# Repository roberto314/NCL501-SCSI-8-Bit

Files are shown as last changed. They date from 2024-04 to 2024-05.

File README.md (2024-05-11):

# NCL501-SCSI-8-Bit
Recreation of a bootable ISA 8-Bit SCSI Card.

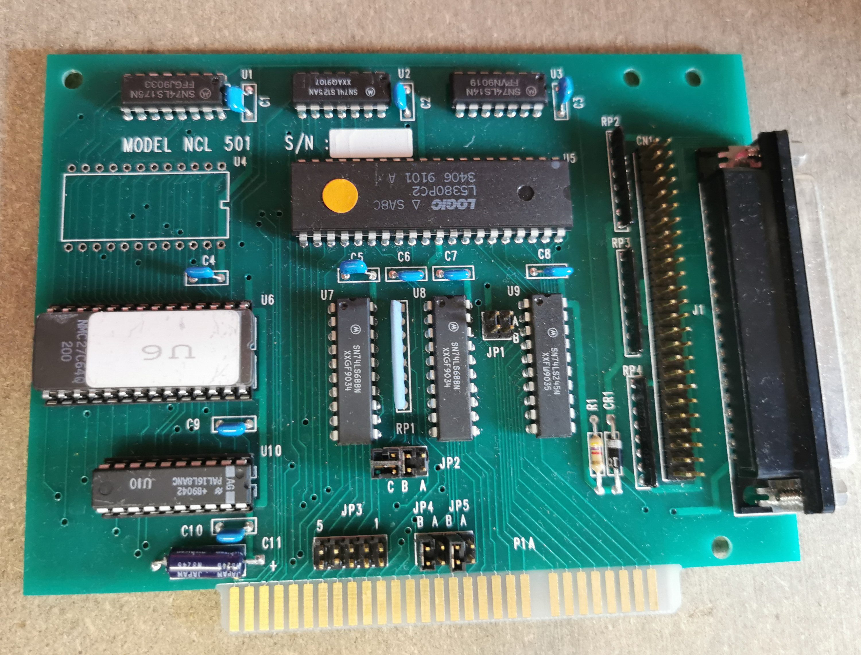
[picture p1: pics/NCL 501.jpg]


There is one PAL on the Card (PAL16L8), it is protected unfortunately.
A dump has been done and the equations have been recreated.
They might be wrong.
BIOS EPROM is a 27C64 Type, RAM is not poplated but a 6116 might be used (24-pin Socket).

[Schematic](schematic/NCL501/pdf/NCL501.pdf)

The new card looks like this:
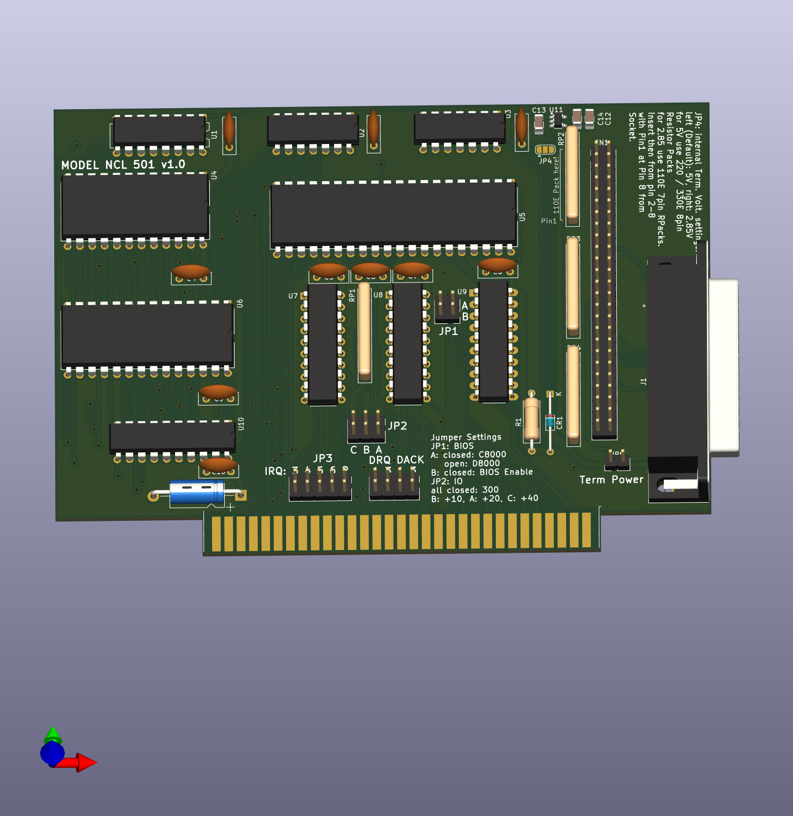
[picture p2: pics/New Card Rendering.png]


or the real thing:
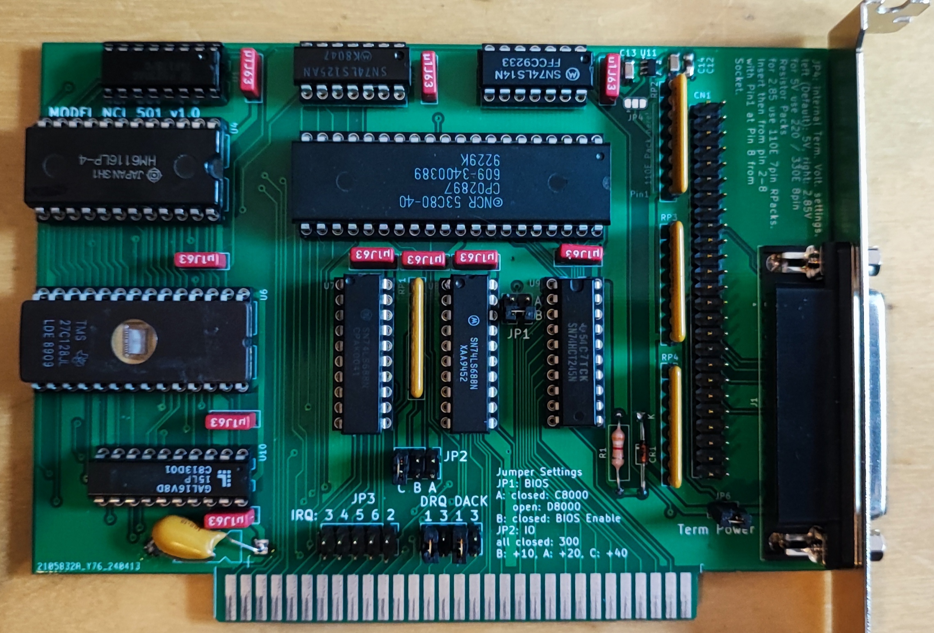
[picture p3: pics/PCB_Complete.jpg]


Changes are:

* active termination or passive Termination possible.
* Term Power with Jumper
* DB25 Connector instead of DB37
* smaller (97.75 x 135mm)

For active Termination the following Parts are needed:

    - C12: 470p Footprint 1206

    - C13, C14: 100n Footprint 1206

    - U11: MIC5219 2.85V Regulator SOT-23-5

This Adapter has some serious shortcomings:

In my Computer (micro8088) it ONLY works with DRQ/DACK 3, ROM @ D8000 and IO @ 330!
IRQ doesn't matter also the RAM onboard is not necessary.

I tested the following Images:

Heads and Sectors working:

spf = sectors/fat, spc = sectors/cluster

* C:  79 / H:8  / S:32 10 MB (FAT12) works
* C:  95 / H:8  / S:32 12 MB (FAT12) works
* C:  39 / H:16 / S:32 10 MB works
* C:  22 / H:15 / S:63 10 MB doesn't work (non-system disk)
* C:  21 / H:16 / S:62 10 MB doesn't work (non-system disk)
* C:  21 / H:16 / S:63 10 MB doesn't work (non-system disk)
* C:  63 / H:16 / S:32 16 MB (FAT12) works
* C:  67 / H:16 / S:32 17 MB (FAT16/4) doesn't work (non-system disk)
* C:  67 / H:16 / S:32 17 MB (FAT16/4) with spf=0x40 instead of 0x100: works
* C: 127 / H:16 / S:32 32 MB (FAT16/4) with spf=0x40 instead of 0x100: works
* C: 135 / H:16 / S:32 33 MB (FAT16/6) with spf=0x60 instead of 0x100: works
* C: 255 / H:16 / S:32 64 MB (FAT16/6) with spf=0x40 instead of 0x100: doesn't work (non-system disk)
* C: 255 / H:16 / S:32 64 MB (FAT16/6) with spf=0x40 instead of 0x100: doesn't work (non-system disk)
* C: 255 / H:16 / S:32 64 MB (FAT16/6) with spf=0x80 instead of 0x100: works
* C: 507 / H:16 / S:32 127 MB (FAT16/6) with spf=0xFF instead of 0x100: doesn't work (non-system disk)
* C: 507 / H:16 / S:32 127 MB (FAT16/6) with spf=0xFE instead of 0x100: doesn't work (non-system disk)
* C: 359 / H:16 / S:32 90 MB (FAT16/6) with spf=0xC0 instead of 0x100, spc=4: doesn't work
* C: 359 / H:16 / S:32 90 MB (FAT16/6) with spf=0xC0 instead of 0x100, spc=8: doesn't work
* C: 183 / H:16 / S:63 90 MB (FAT16/6) with spf=0xC0 instead of 0x100: doesn't work (non-system disk)
* C: 359 / H:16 / S:32 90 MB (FAT16/6) with spf=0xD0 instead of 0x100: doesn't work, hangs
* C: 359 / H:16 / S:32 90 MB (FAT16/6) with spf=0xE0 instead of 0x100: doesn't work, hangs
* C: 479 / H:16 / S:32 120 MB (FAT16/6) with spf=0xF0 instead of 0x100: doesn't work (non-system disk)
* C: 511 / H:16 / S:32 128 MB (FAT16/6) with spf=0xC0 instead of 0x100: doesn't work
* C: 511 / H:16 / S:32 128 MB (FAT16/6) with spf=0x80, spc=8 instead of 0x100: works
* C: 515 / H:16 / S:32 129 MB (FAT16/6) with spf=0xC0 instead of 0x100: doesn't work
* C: 763 / H:16 / S:32 191 MB (FAT16/6) with spf=0xC0 instead of 0x100: doesn't work
* C: 767 / H:16 / S:32 192 MB (FAT16/6) with spf=0xC0 instead of 0x100: doesn't work
* C:1019 / H:16 / S:32 255 MB (FAT16/6) with spf=0x80,spc=16  works
* C:1023 / H:16 / S:32 256 MB (FAT16/6) with spf=0x80,spc=16  works
* C: 741 / H:16 / S:33 191 MB (FAT16/6) with spf=0xC0 instead of 0x100: doesn't work (non-system disk)
* C: 1006 / H:14 / S:48 330 MB (FAT16/6) with spf=0xC0 instead of 0x100: doesn't work (non-system disk)
* C:  510 / H:16 / S:48 191 MB (FAT16/6) with spf=0xC0 instead of 0x100: doesn't work (non-system disk)
* C:  620 / H:16 / S:62 300 MB (FAT16/6) with spf=0x100,spc=16: doesn't work (non-system disk)
* C:  620 / H:16 / S:62 300 MB (FAT16/6) with spf=0x80,spc=32: doesn't work (non-system disk)
* C:  620 / H:16 / S:62 300 MB (FAT16/6) with spf=0x80,spc=32: doesn't work (non-system disk)
* C:  262 / H:16 / S:63 300 MB (FAT16/6) with spf=0xFC,spc=16: doesn't work (non-system disk)
* C:  262 / H:16 / S:63 300 MB (FAT16/6) with spf=0xC0,spc=16: doesn't work (non-system disk)
* C:  514 / H:32 / S:32 257.5 MB (FAT16/6) with spf=0xFC,spc=16  works
* C: 1005 / H:32 / S:32 503 MB (FAT16/6) with spf=0xFC,spc=16  works
* C: 1001 / H:5 / S:52 127 MB (FAT16/6) with spf=0xC0,spc=8 doesn't work (non-system disk)
* C: 1001 / H:5 / S:52 127 MB (FAT16/6) with spf=0xFC,spc=8 doesn't work (non-system disk)
 
* C: 127 / H:16 / S:32 32 MB doesn't work (non-system disk)
* C: 479 / H:8  / S:32 60 MB doesn't work (non-system disk)
* C: 511 / H:8  / S:32 64 MB doesn't work (non-system disk)
* C: 197 / H:32 / S:32 99 MB (FAT16/4) with spf=0xC0 instead of 0x100: doesn't work (non-system disk)
* C:1023 / H:8  / S:32 128 MB doesn't work (non-system disk)
* C:1023 / H:16 / S:32 256 MB doesn't work (non-system disk)
* C:1019 / H:16 / S:32 255 MB doesn't work (non-system disk)
* C: 511 / H:16 / S:32 128 MB doesn't work (non-system disk)
* C: 511 / H:16 / S:32 128 MB (FAT16/4) with spf=0x40 instead of 0x100: doesn't work (non-system disk)
* C: 503 / H:16 / S:32 126 MB (FAT16/4) with spf=0x40 instead of 0x100: doesn't work (non-system disk)

Limits are: 

* spf Value only 8-bit and only some values are possible.
* Size 503MB for now.

The Card can be hacked to be a SUMO SCSI Card with reasonable effort (by omitting U12-14). Then the ASPI Driver ZHA.SYS and ZDRV.SYS will work.

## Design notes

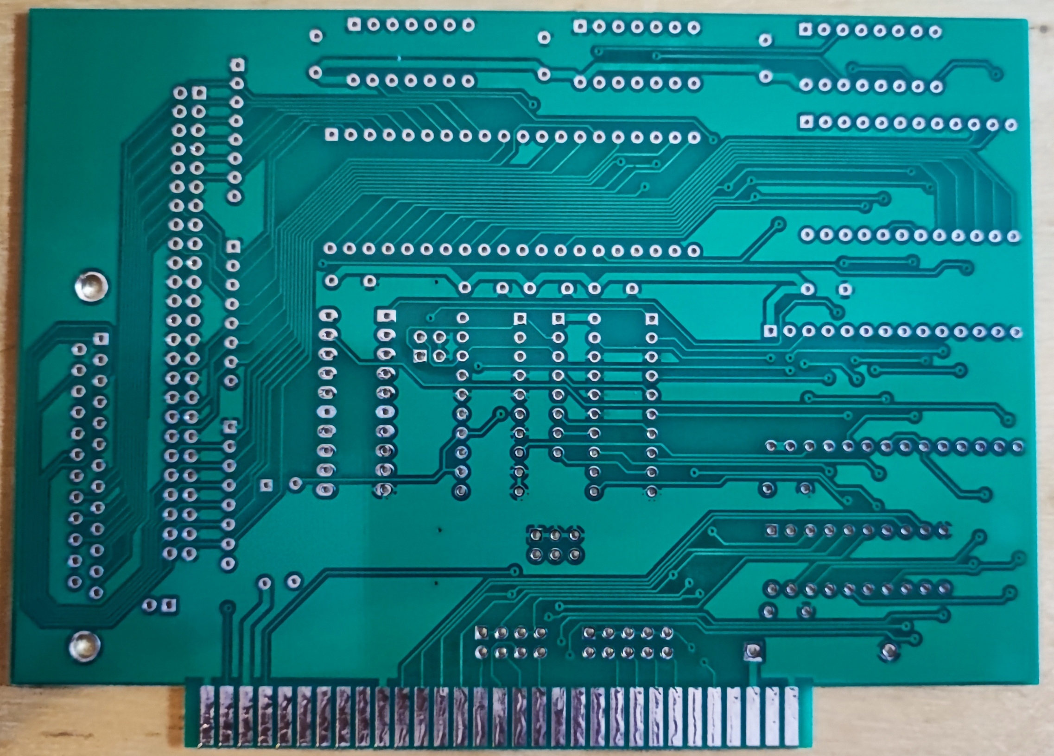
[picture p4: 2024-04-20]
pics/PCB_Back.jpg

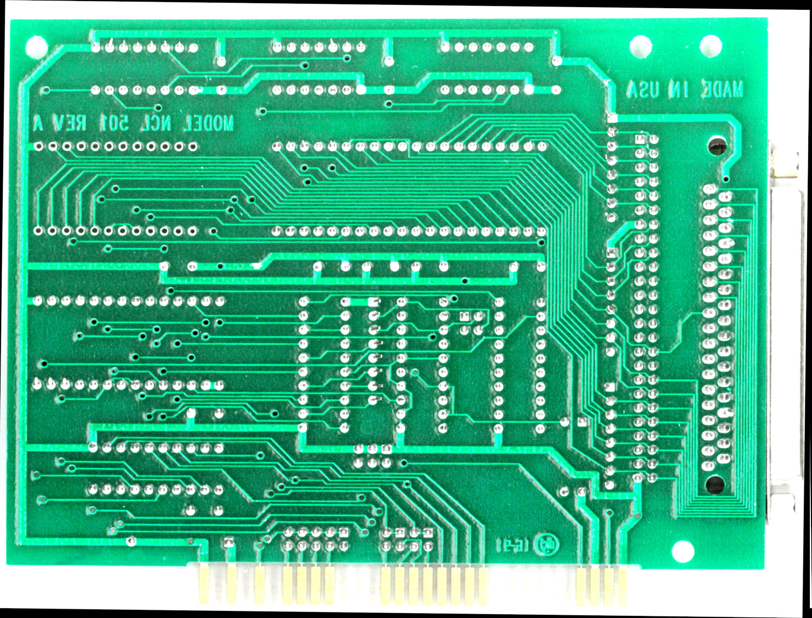
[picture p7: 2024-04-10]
pics/NCL-501_back_lo.jpg

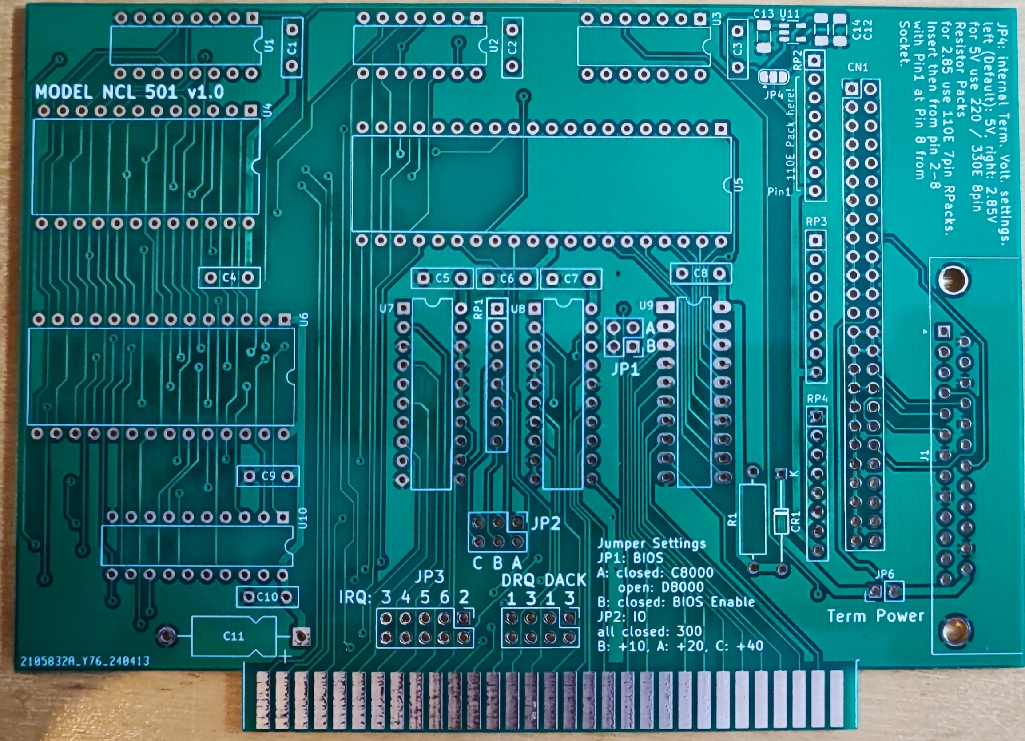
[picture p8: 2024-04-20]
pics/PCB_Front.jpg

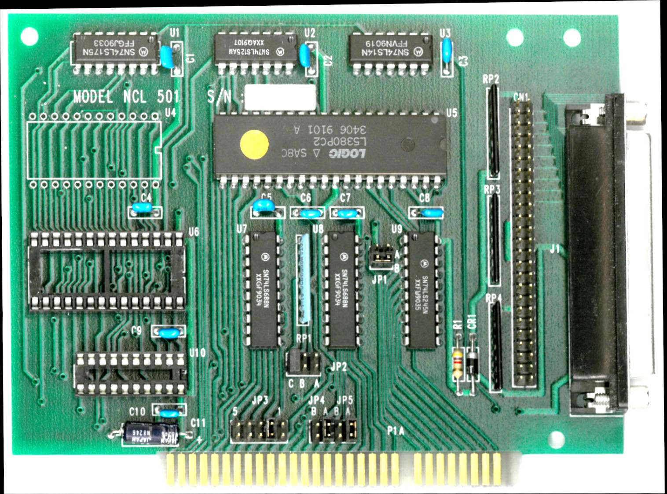
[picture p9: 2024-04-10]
pics/NCL-501_front_lo.jpg

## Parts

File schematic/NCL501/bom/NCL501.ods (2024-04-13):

References | Value | Footprint | Quantity
C1, C2, C3, C4, C5, C6, C7, C8, C9, C10 | 100n | C_Disc_D8.0mm_W2.5mm_P5.00mm | 10
C13, C14 | 100n | C_1206_3216Metric_Pad1.33x1.80mm_HandSolder | 2
C11 | 22u/16 | CP_Axial_L11.0mm_D5.0mm_P18.00mm_Horizontal | 1
C12 | 470p | C_1206_3216Metric_Pad1.33x1.80mm_HandSolder | 1
R1 | 4k7 | R_Axial_DIN0309_L9.0mm_D3.2mm_P12.70mm_Horizontal | 1
U7, U8 | 74LS688 | DIP-20_W7.62mm | 2
U1 | 74LS175 | DIP-16_W7.62mm | 1
U2 | 74LS125 | DIP-14_W7.62mm | 1
U3 | 74LS14 | DIP-14_W7.62mm | 1
U4 | 6116 | DIP-24_W15.24mm | 1
U5 | 53C80 | DIP-40_W15.24mm | 1
U6 | 27C128 | DIP-28_W15.24mm | 1
U9 | 74LS245 | DIP-20_W7.62mm_LongPads | 1
U10 | PAL16L8 | DIP-20_W7.62mm | 1
U11 | MIC5219-2.85YM5 | SOT-23-5 | 1
RP2, RP3, RP4 | 220E/330E | R_Array_SIP8 | 3
CN1 | SCSI Intern | PinHeader_2x25_P2.54mm_Vertical | 1
CR1 | 1N4001 | D_DO-34_SOD68_P12.70mm_Horizontal | 1
JP1 | BIOS | PinHeader_2x02_P2.54mm_Vertical | 1
JP2 | IO | PinHeader_2x03_P2.54mm_Vertical | 1
JP3 | IRQ | PinHeader_2x05_P2.54mm_Vertical | 1
JP4 | TRMPWRSEL | SolderJumper-3_P1.3mm_Bridged12_RoundedPad1.0x1.5mm | 1
JP6 | TermPower | PinHeader_1x02_P2.54mm_Vertical | 1
RP1 | 4k7 | R_Array_SIP8 | 1
J1 | SCSI extern | DSUB-25_Female_Horizontal_P2.77x2.84mm_EdgePinOffset7.70mm_Housed_MountingHolesOffset9.12mm | 1
J2 | Bus_ISA_8bit | BUS_XT | 1
J4 | DACK/DRQ | PinHeader_2x04_P2.54mm_Vertical | 1

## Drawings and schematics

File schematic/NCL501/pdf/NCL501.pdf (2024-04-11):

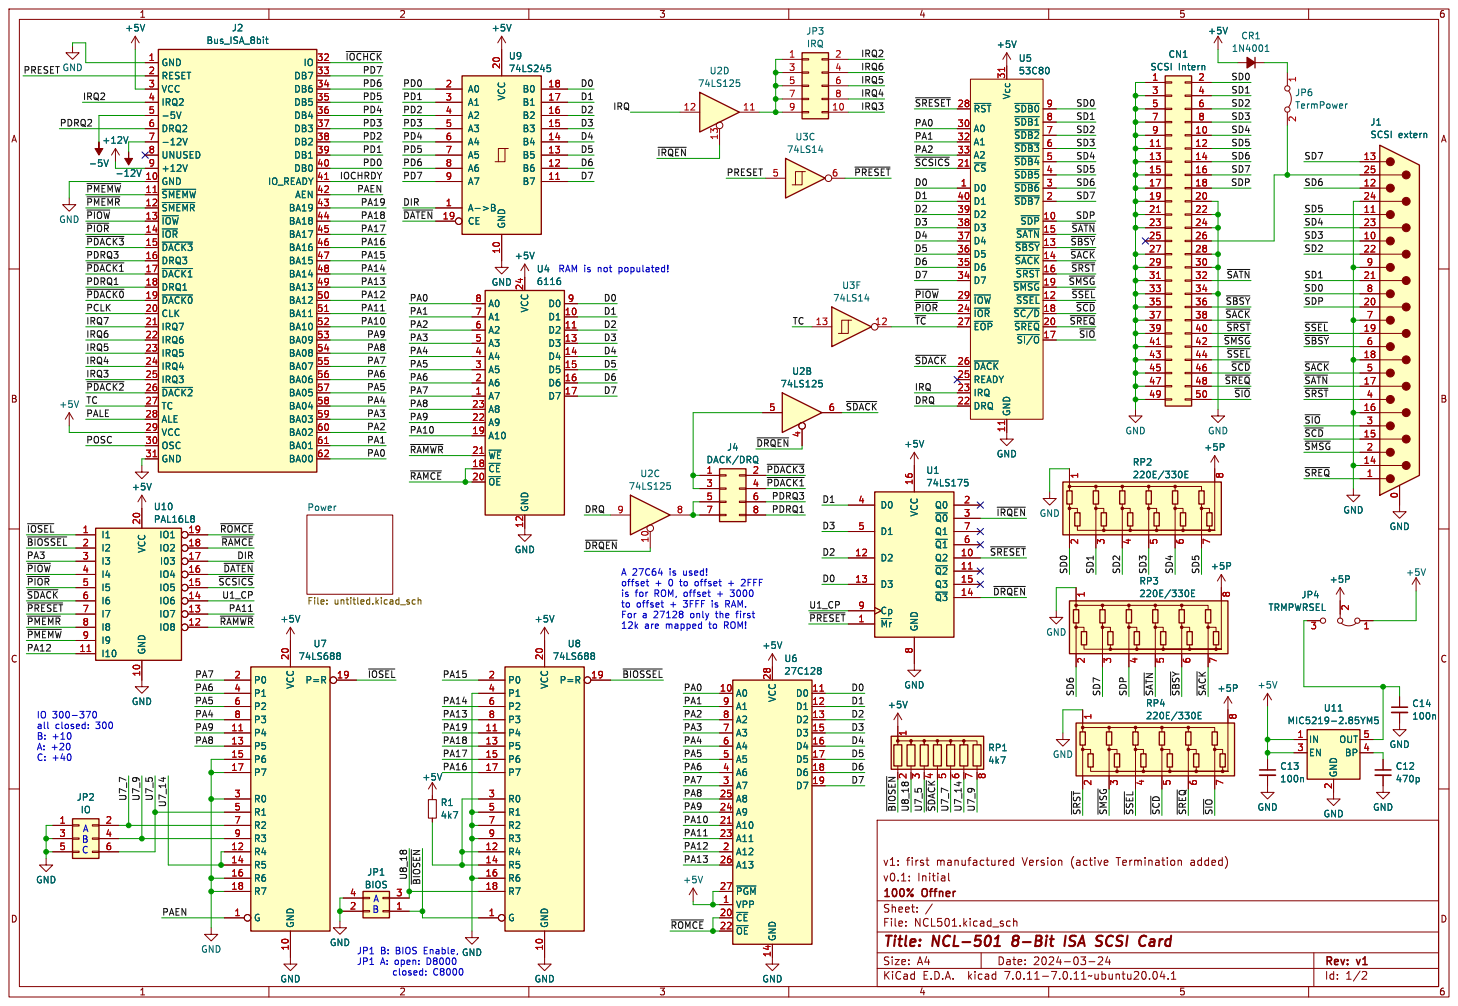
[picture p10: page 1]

J2 Bus_ISA_8bit GND 1 GND 10 ~{SMEMW} 11 ~{SMEMR} 12 ~{IOW} 13 ~{IOR} 14 ~{DACK3} 15 DRQ3 16 ~{DACK1} 17 DRQ1 18 ~{DACK0} 19 RESET 2 CLK 20
IRQ3 25 ~{DACK2} 26 TC 27 ALE 28 VCC 29 VCC 3 OSC 30 GND 31

J2 Bus_ISA_8bit

74LS125 GND 1 GND 10 ~{SMEMW} 11 ~{SMEMR} 12 ~{IOW} 13 ~{IOR} 14 ~{DACK3} 15 DRQ3 16 ~{DACK1} 17 DRQ1 18 ~{DACK0} 19 RESET 2 CLK 20

to offset + 3FFF is RAM. For a 27128 only the first 12k are mapped to ROM! RAM is not populated!

2 EN 3 BP 4 OUT 5 U11 MIC5219-2.85YM5 +5V GND GND

A 27C64 is used! offset + 0 to offset + 2FFF

is for ROM, offset + 3000

2 EN 3 BP 4 OUT 5 GND

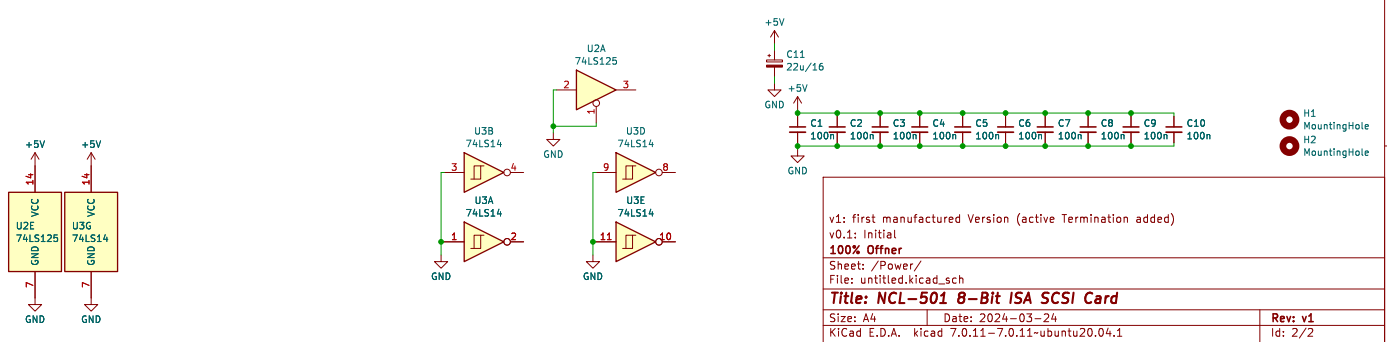
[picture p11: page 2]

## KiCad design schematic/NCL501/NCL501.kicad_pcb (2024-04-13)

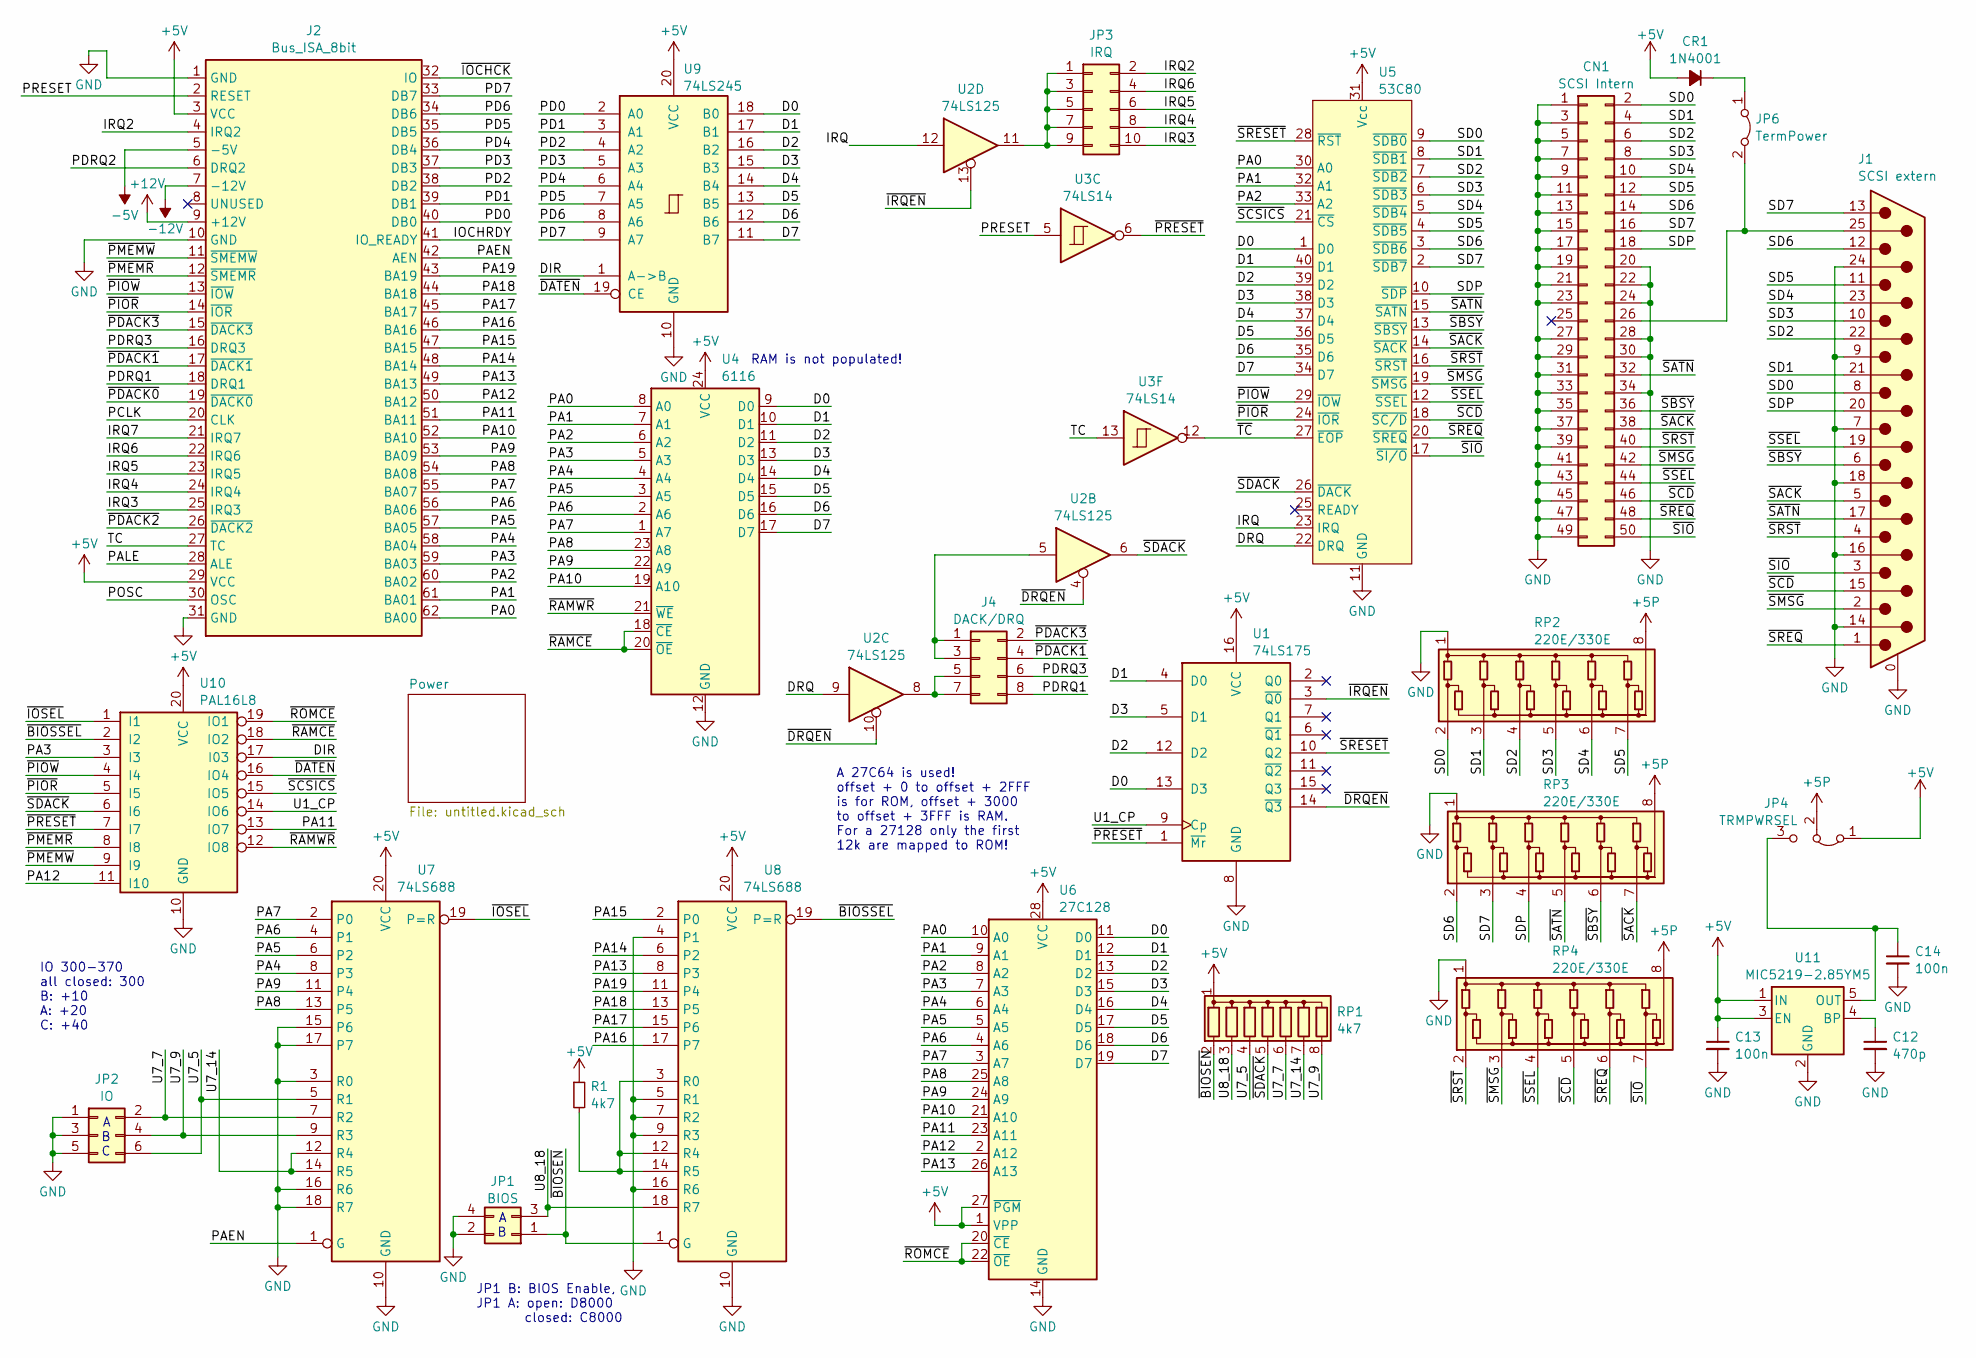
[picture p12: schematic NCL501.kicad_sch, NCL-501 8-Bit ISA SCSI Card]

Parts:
C12: 470p; C_1206_3216Metric_Pad1.33x1.80mm_HandSolder
C13, C14: 100n; C_1206_3216Metric_Pad1.33x1.80mm_HandSolder
CN1: SCSI Intern; PinHeader_2x25_P2.54mm_Vertical
CR1: 1N4001; D_DO-34_SOD68_P12.70mm_Horizontal
J1: SCSI extern; DSUB-25_Female_Horizontal_P2.77x2.84mm_EdgePinOffset7.70mm_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
J2: Bus_ISA_8bit; BUS_XT
J4: DACK/DRQ; PinHeader_2x04_P2.54mm_Vertical
JP1: BIOS; PinHeader_2x02_P2.54mm_Vertical
JP2: IO; PinHeader_2x03_P2.54mm_Vertical
JP3: IRQ; PinHeader_2x05_P2.54mm_Vertical
JP4: TRMPWRSEL; SolderJumper-3_P1.3mm_Bridged12_RoundedPad1.0x1.5mm
JP6: TermPower; PinHeader_1x02_P2.54mm_Vertical
R1: 4k7; R_Axial_DIN0309_L9.0mm_D3.2mm_P12.70mm_Horizontal
RP1: 4k7; R_Array_SIP8
RP2, RP3, RP4: 220E/330E; R_Array_SIP8
U1: 74LS175; DIP-16_W7.62mm
U2: 74LS125; DIP-14_W7.62mm
U3: 74LS14; DIP-14_W7.62mm
U4: 6116; DIP-24_W15.24mm
U5: 53C80; DIP-40_W15.24mm
U6: 27C128; DIP-28_W15.24mm
U7, U8: 74LS688; DIP-20_W7.62mm
U9: 74LS245; DIP-20_W7.62mm_LongPads
U10: PAL16L8; DIP-20_W7.62mm
U11: MIC5219-2.85YM5; SOT-23-5

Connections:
+5P: JP4.2 (C), RP2.8 (COM2), RP3.8 (COM2), RP4.8 (COM2)
+5V: C13.1, CR1.2 (A), J2.3 (VCC), J2.29 (VCC), JP4.1 (A), R1.1, RP1.1 (common), U1.16 (VCC), U4.24 (VCC), U5.31 (Vcc), U6.1 (VPP), U6.27 (~PGM), U6.28 (VCC), U7.20 (VCC), U8.20 (VCC), U9.20 (VCC), U10.20 (VCC), U11.1 (IN), U11.3 (EN); also elsewhere on the board
+12V: J2.9 (+12V)
-5V: J2.5 (-5V)
-12V: J2.7 (-12V)
/D0: U1.13 (D3), U4.9 (D0), U5.1 (D0), U6.11 (D0), U9.18 (B0)
/D1: U1.4 (D0), U4.10 (D1), U5.40 (D1), U6.12 (D1), U9.17 (B1)
/D2: U1.12 (D2), U4.11 (D2), U5.39 (D2), U6.13 (D2), U9.16 (B2)
/D3: U1.5 (D1), U4.13 (D3), U5.38 (D3), U6.15 (D3), U9.15 (B3)
/D4: U4.14 (D4), U5.37 (D4), U6.16 (D4), U9.14 (B4)
/D5: U4.15 (D5), U5.36 (D5), U6.17 (D5), U9.13 (B5)
/D6: U4.16 (D6), U5.35 (D6), U6.18 (D6), U9.12 (B6)
/D7: U4.17 (D7), U5.34 (D7), U6.19 (D7), U9.11 (B7)
/DIR: U9.1 (A->B), U10.17 (I03)
/DRQ: U2.9, U5.22 (DRQ)
/IOCHRDY: J2.41 (IO_READY)
/IRQ: U2.12, U5.23 (IRQ)
/IRQ2: J2.4 (IRQ2), JP3.2
/IRQ3: J2.25 (IRQ3), JP3.10
/IRQ4: J2.24 (IRQ4), JP3.8
/IRQ5: J2.23 (IRQ5), JP3.6
/IRQ6: J2.22 (IRQ6), JP3.4
/IRQ7: J2.21 (IRQ7)
/PA0: J2.62 (BA00), U4.8 (A0), U5.30 (A0), U6.10 (A0)
/PA1: J2.61 (BA01), U4.7 (A1), U5.32 (A1), U6.9 (A1)
/PA2: J2.60 (BA02), U4.6 (A2), U5.33 (A2), U6.8 (A2)
/PA3: J2.59 (BA03), U4.5 (A3), U6.7 (A3), U10.3 (I3)
/PA4: J2.58 (BA04), U4.4 (A4), U6.6 (A4), U7.8 (P3)
/PA5: J2.57 (BA05), U4.3 (A5), U6.5 (A5), U7.6 (P2)
/PA6: J2.56 (BA06), U4.2 (A6), U6.4 (A6), U7.4 (P1)
/PA7: J2.55 (BA07), U4.1 (A7), U6.3 (A7), U7.2 (P0)
/PA8: J2.54 (BA08), U4.23 (A8), U6.25 (A8), U7.13 (P5)
/PA9: J2.53 (BA09), U4.22 (A9), U6.24 (A9), U7.11 (P4)
/PA10: J2.52 (BA10), U4.19 (A10), U6.21 (A10)
/PA11: J2.51 (BA11), U6.23 (A11), U10.13 (IO7)
/PA12: J2.50 (BA12), U6.2 (A12), U10.11 (I10)
/PA13: J2.49 (BA13), U6.26 (A13), U8.8 (P3)
/PA14: J2.48 (BA14), U8.6 (P2)
/PA15: J2.47 (BA15), U8.2 (P0)
/PA16: J2.46 (BA16), U8.17 (P7)
/PA17: J2.45 (BA17), U8.15 (P6)
/PA18: J2.44 (BA18), U8.13 (P5)
/PA19: J2.43 (BA19), U8.11 (P4)
/PAEN: J2.42 (AEN), U7.1 (G)
/PALE: J2.28 (ALE)
/PCLK: J2.20 (CLK)
/PD0: J2.40 (DB0), U9.2 (A0)
/PD1: J2.39 (DB1), U9.3 (A1)
/PD2: J2.38 (DB2), U9.4 (A2)
/PD3: J2.37 (DB3), U9.5 (A3)
/PD4: J2.36 (DB4), U9.6 (A4)
/PD5: J2.35 (DB5), U9.7 (A5)
/PD6: J2.34 (DB6), U9.8 (A6)
/PD7: J2.33 (DB7), U9.9 (A7)
/PDRQ1: J2.18 (DRQ1), J4.8
/PDRQ2: J2.6 (DRQ2)
/PDRQ3: J2.16 (DRQ3), J4.6
/POSC: J2.30 (OSC)
/PRESET: J2.2 (RESET), U3.5
/SD0: CN1.2, J1.8, RP2.2 (R1), U5.9 (~SDB0)
/SD1: CN1.4, J1.21, RP2.3 (R2), U5.8 (~SDB1)
/SD2: CN1.6, J1.22, RP2.4 (R3), U5.7 (~SDB2)
/SD3: CN1.8, J1.10, RP2.5 (R4), U5.6 (~SDB3)
/SD4: CN1.10, J1.23, RP2.6 (R5), U5.5 (~SDB4)
/SD5: CN1.12, J1.11, RP2.7 (R6), U5.4 (~SDB5)
/SD6: CN1.14, J1.12, RP3.2 (R1), U5.3 (~SDB6)
/SD7: CN1.16, J1.13, RP3.3 (R2), U5.2 (~SDB7)
/SDP: CN1.18, J1.20, RP3.4 (R3), U5.10 (~SDP)
/TC: J2.27 (TC), U3.13
/U1_CP: U1.9 (Cp), U10.14 (IO6)
/U7_5: JP2.6, RP1.4 (R3), U7.5 (R1)
/U7_7: JP2.2, RP1.6 (R5), U7.7 (R2)
/U7_9: JP2.4, RP1.8 (R7), U7.9 (R3)
/U7_14: RP1.7 (R6), U7.12 (R4), U7.14 (R5)
/U8_18: JP1.3, RP1.3 (R2), U8.18 (R7)
/~BIOSEN: JP1.1, RP1.2 (R1), U8.1 (G)
/~BIOSSEL: U8.19 (P=R), U10.2 (I2)
/~DATEN: U9.19 (CE), U10.16 (IO4)
/~DRQEN: U1.14 (~Q3), U2.4, U2.10
/~IOCHCK: J2.32 (IO)
/~IOSEL: U7.19 (P=R), U10.1 (I1)
/~IRQEN: U1.3 (~Q0), U2.13
/~PDACK0: J2.19 (~DACK0)
/~PDACK1: J2.17 (~DACK1), J4.4
/~PDACK2: J2.26 (~DACK2)
/~PDACK3: J2.15 (~DACK3), J4.2
/~PIOR: J2.14 (~IOR), U5.24 (~IOR), U10.5 (I5)
/~PIOW: J2.13 (~IOW), U5.29 (~IOW), U10.4 (I4)
/~PMEMR: J2.12 (~SMEMR), U10.8 (I8)
/~PMEMW: J2.11 (~SMEMW), U10.9 (I9)
/~PRESET: U1.1 (~Mr), U3.6, U10.7 (I7)
/~RAMCE: U4.18 (~CE), U4.20 (~OE), U10.18 (IO2)
/~RAMWR: U4.21 (~WE), U10.12 (IO8)
/~ROMCE: U6.20 (~CE), U6.22 (~OE), U10.19 (IO1)
/~SACK: CN1.38, J1.5, RP3.7 (R6), U5.14 (~SACK)
/~SATN: CN1.32, J1.17, RP3.5 (R4), U5.15 (~SATN)
/~SBSY: CN1.36, J1.6, RP3.6 (R5), U5.13 (~SBSY)
/~SCD: CN1.46, J1.15, RP4.5 (R4), U5.18 (~SC/D)
/~SCSICS: U5.21 (~CS), U10.15 (IO5)
/~SDACK: RP1.5 (R4), U2.6, U5.26 (~DACK), U10.6 (I6)
/~SIO: CN1.50, J1.3, RP4.7 (R6), U5.17 (~SI/O)
/~SMSG: CN1.42, J1.2, RP4.3 (R2), U5.19 (~SMSG)
/~SREQ: CN1.48, J1.1, RP4.6 (R5), U5.20 (~SREQ)
/~SRESET: U1.10 (Q2), U5.28 (~RST)
/~SRST: CN1.40, J1.4, RP4.2 (R1), U5.16 (~SRST)
/~SSEL: CN1.44, J1.19, RP4.4 (R3), U5.12 (~SSEL)
/~TC: U3.12, U5.27 (~EOP)
GND: C12.2, C13.2, C14.2, CN1.1, CN1.3, CN1.5, CN1.7, CN1.9, CN1.11, CN1.13, CN1.15, CN1.17, CN1.19, CN1.20, CN1.21, CN1.22, CN1.23, CN1.24, CN1.27, CN1.28, CN1.29, CN1.30, CN1.31, CN1.33, CN1.34, CN1.35, CN1.37, CN1.39, CN1.41, CN1.43, CN1.45, CN1.47, CN1.49, J1.0 (PAD), J1.7, J1.9, J1.14, J1.16, J1.18, J1.24, J2.1 (GND), J2.10 (GND), J2.31 (GND), JP1.2, JP1.4, JP2.1, JP2.3, JP2.5, RP2.1 (COM1), RP3.1 (COM1), RP4.1 (COM1), U1.8 (GND), U4.12 (GND), U5.11 (GND), U6.14 (GND), U7.3 (R0), U7.10 (GND), U7.15 (P6), U7.16 (R6), U7.17 (P7), U7.18 (R7), U8.4 (P1), U8.5 (R1), U8.7 (R2), U8.9 (R3), U8.10 (GND), U8.16 (R6), U9.10 (GND), U10.10 (GND), U11.2 (GND); also elsewhere on the board
unnamed: CN1.26, J1.25, JP6.2 (B)
unnamed: CR1.1 (K), JP6.1 (A)
unnamed: J4.1, J4.3, U2.5
unnamed: J4.5, J4.7, U2.8
unnamed: JP3.1, JP3.3, JP3.5, JP3.7, JP3.9, U2.11
unnamed: C14.1, JP4.3 (B), U11.5 (OUT)
unnamed: R1.2, U8.3 (R0), U8.12 (R4), U8.14 (R5)
unnamed: C12.1, U11.4 (BP)

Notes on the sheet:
A B C
RAM is not populated!
IO 300-370 all closed: 300 B: +10 A: +20 C: +40
A 27C64 is used! offset + 0 to offset + 2FFF is for ROM, offset + 3000 to offset + 3FFF is RAM. For a 27128 only the first 12k are mapped to ROM!
JP1 B: BIOS Enable, JP1 A: open: D8000 closed: C8000
A B

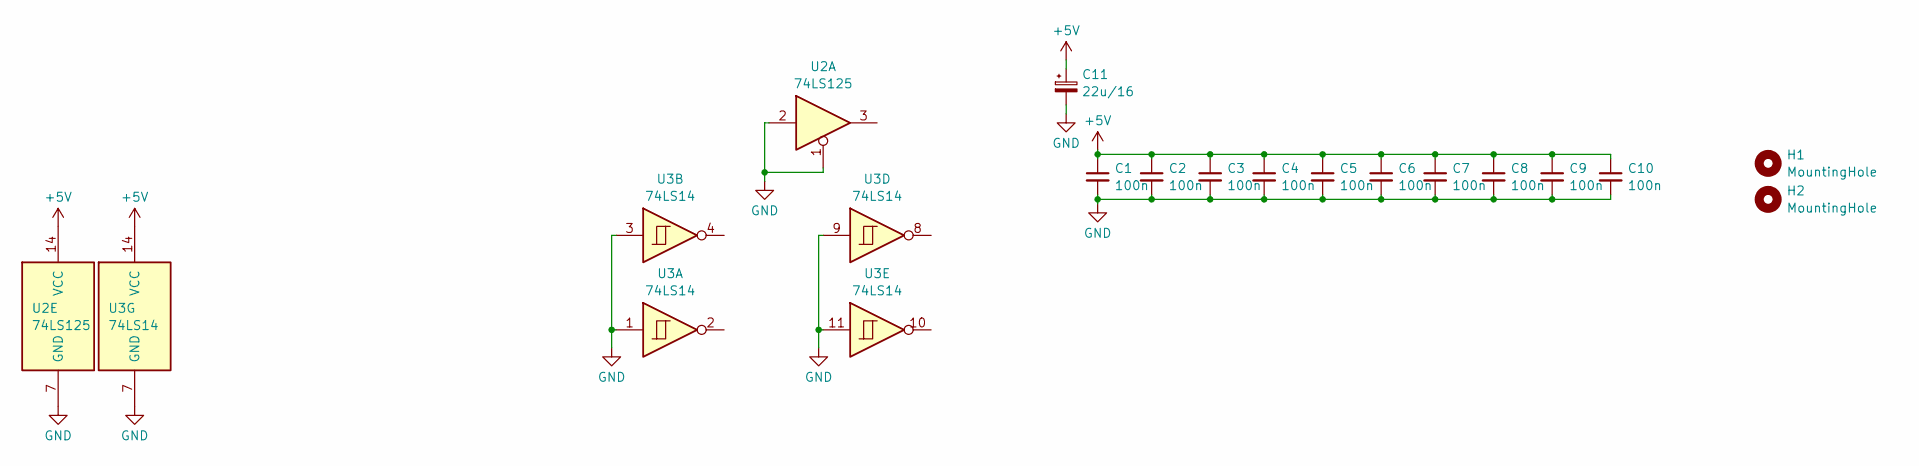
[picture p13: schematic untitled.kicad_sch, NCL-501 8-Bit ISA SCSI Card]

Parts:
C1, C2, C3, C4, C5, C6, C7, C8, C9, C10: 100n; C_Disc_D8.0mm_W2.5mm_P5.00mm
C11: 22u/16; CP_Axial_L11.0mm_D5.0mm_P18.00mm_Horizontal
H1, H2: MountingHole; MountingHole_3.5mm
U2: 74LS125; DIP-14_W7.62mm
U3: 74LS14; DIP-14_W7.62mm

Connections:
+5V: C1.1, C2.1, C3.1, C4.1, C5.1, C6.1, C7.1, C8.1, C9.1, C10.1, C11.1, U2.14 (VCC), U3.14 (VCC); also elsewhere on the board
GND: C1.2, C2.2, C3.2, C4.2, C5.2, C6.2, C7.2, C8.2, C9.2, C10.2, C11.2, U2.1, U2.2, U2.7 (GND), U3.1, U3.3, U3.7 (GND), U3.9, U3.11; also elsewhere on the board

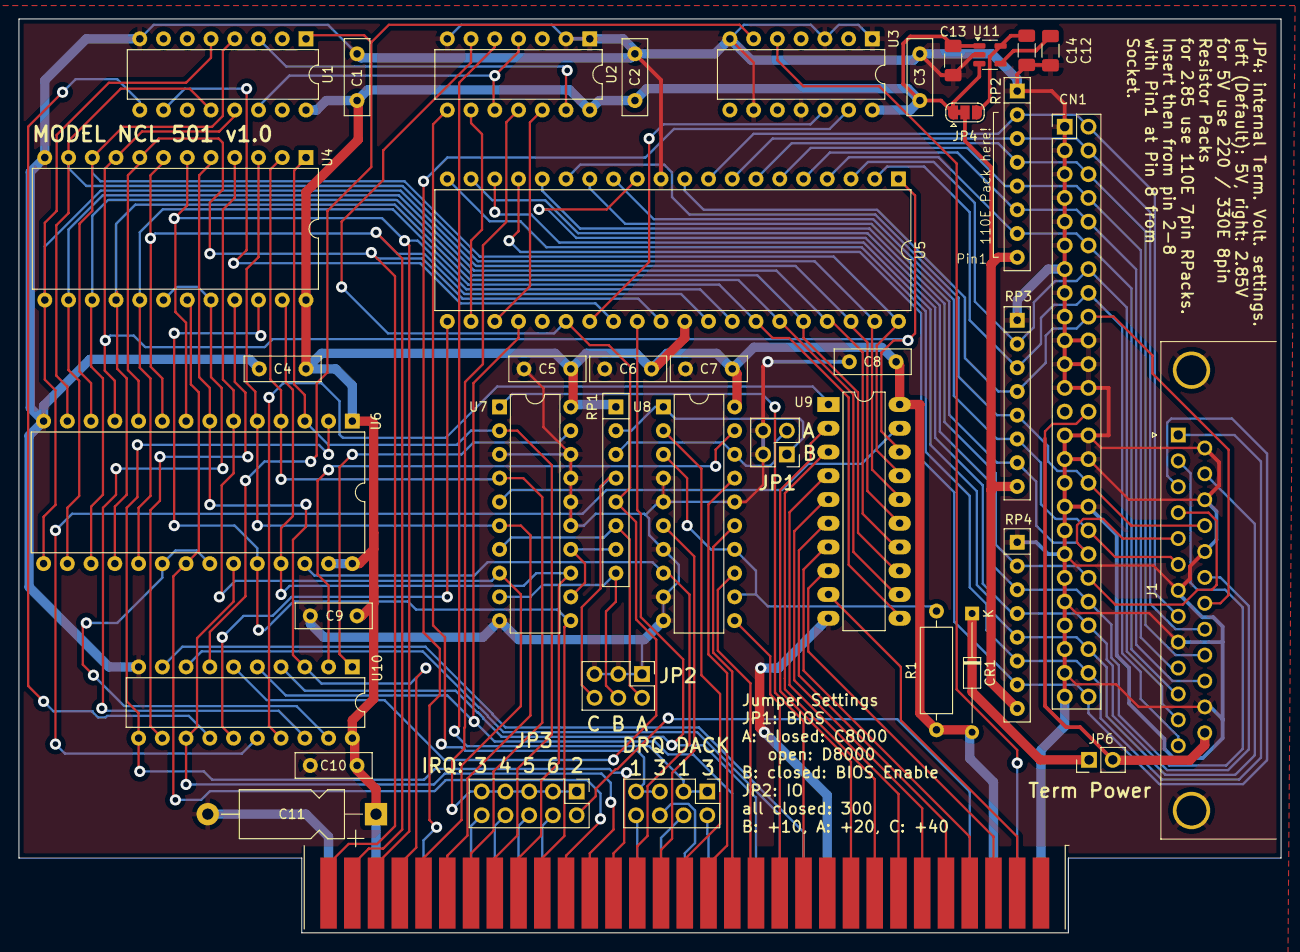
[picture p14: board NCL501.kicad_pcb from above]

Board: 2 copper layers, 135.0 x 97.8 mm, 42 parts (0 on the bottom side), 104 nets.

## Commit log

2024-04-11 first manufactured Version
    [NCL501.kicad_pcb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]
2024-04-11 pics updated
    [NCL501-B_Cu.gbr, NCL501-B_Fab.gbr, NCL501-B_Silkscreen.gbr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]
2024-04-11 Schematic updated
    [NCL501.kicad_pcb, NCL501.kicad_sch, untitled.kicad_sch]
2024-04-13 manufacturing data update
    [NCL501-B_Cu.gbr, NCL501-B_Fab.gbr, NCL501-B_Silkscreen.gbr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]
2024-04-23 card works, more testing needed
    [NCL501.kicad_sch]
